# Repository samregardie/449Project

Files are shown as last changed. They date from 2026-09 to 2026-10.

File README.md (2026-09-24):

# 18-449 Project

Lab 2 firmware for the STM32 Nucleo-F401RE, built with Zephyr.

- `lab2/stm32/`: the Zephyr app
- `setup449`: shell setup script (see [Every new shell](#every-new-shell))

This repo sits inside a west workspace:

```
zephyrproject/     ← west workspace (not tracked): .venv/ .west/ zephyr/ modules/
└── 449Project/           ← this repo
```

## One-time setup

1. Follow the [Zephyr getting-started guide](https://docs.zephyrproject.org/latest/develop/getting_started/index.html) to install the host dependencies and the Zephyr SDK.
2. Install [STM32CubeProgrammer](https://www.st.com/en/development-tools/stm32cubeprog.html) (for `west flash`) and OpenOCD (for `west debug`; on macOS run `brew install openocd`).
3. Create the workspace and clone this repo into it:
   ```sh
   mkdir zephyrproject && cd zephyrproject
   python3 -m venv .venv
   source .venv/bin/activate
   pip install west
   west init -m https://github.com/zephyrproject-rtos/zephyr .
   west update
   west packages pip --install
   git clone <this-repo-url> 449Project
   ```

## Every new shell

Run from `449Project/` (bash or zsh):

```sh
source ./setup449
```

It must be sourced, not executed. It activates the west venv and the Zephyr environment.
## Check that your setup works

Build and flash a stock Zephyr sample. The green LED (LD2) should blink:

```sh
west build -p always -b nucleo_f401re ../zephyr/samples/basic/blinky
west flash
```

## Build, flash, debug our app

Run from `449Project/`:

```sh
west build -p always -b nucleo_f401re lab2/stm32   # full rebuild
west flash
west debugserver                                   # terminal 1
west debug                                         # terminal 2
```

For debugging, build with optimizations off:

```sh
west build -p always -b nucleo_f401re lab2/stm32 -- -DCONFIG_DEBUG_OPTIMIZATIONS=y -DCONFIG_DEBUG_THREAD_INFO=y
```

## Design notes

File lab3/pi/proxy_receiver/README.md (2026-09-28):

Code copied from https://github.com/RockyShaikh/logitech-wheel-dev-updated-f26

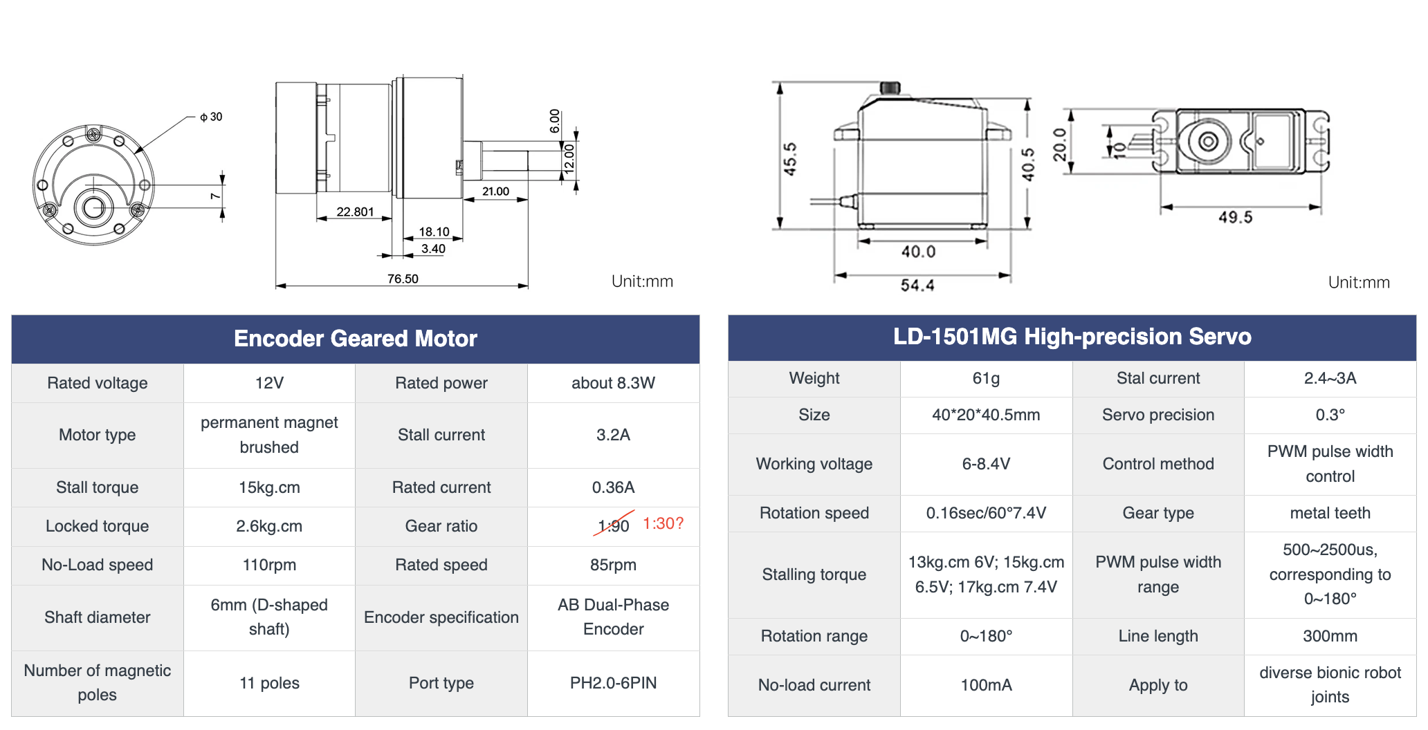
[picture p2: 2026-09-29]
docs/Encoder, Servo datasheet.png

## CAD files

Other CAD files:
docs/CAN Layout.dwg

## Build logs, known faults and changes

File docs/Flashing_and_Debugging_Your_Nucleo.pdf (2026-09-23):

# Flashing and Debugging Your Nucleo

# Installing the Necessary Tools

In order to flash and debug your Nucleo with west, you need to install the proper tooling first. You will need to install the following:

Tool | Description | Notes
STM32CubeProgrammer (https://www.st.com/en/development-tools/stm32cubeprog.html) | STM32CubeProgrammer (STM32CubeProg) is an all-in-one multi-OS software tool for programming STM32 products. | This is required
openocd (https://docs.zephyrproject.org/latest/develop/flash_debug/host-tools.html#runner-openocd) | OpenOCD is a community open source project that provides GDB remote debugging and flash programming support for a wide range of SoCs. | Already installed through Zephyr SDK if using Linux.

## Note about JLink

Some of you may be tempted to use the STM reflasher to flash the JLink firmware onto the STLink. Please do not do that. These boards will eventually get passed down to 18-349, and it may break their workflow.

## References

- Nucleo F401RE (https://docs.zephyrproject.org/latest/boards/st/nucleo_f401re/doc/index.html)

# Setting up your developer environment (every time you open a new terminal)

Every time you open a new terminal, you need to run the following:

Shell

Swift

Shell

# === Linux/Mac ===

# Source the Python environment source .venv/bin/active

# Source the Zephyr environment source zephyr/zephyr-env.sh

# === Windows ===

# Activate the Python environment .venv\Scripts\activate.bat

# Source the Zephyr environment zephyr/zephyr-env.cmd

# Flashing

Flashing your board is very simple. You just run the following command:

west flash

More information on the flash command can be found here. (https://docs.zephyrproject.org/latest/develop/west/build-flash-debug.html#flashing-west-flash)

# Debugging

Debugging on this board can be tedious. You will need two terminals. One for the debug server, and the other for the debugging session. Run the following commands:

# In terminal 1

west debugserver

# In terminal 2

west debug

Shell

Shell

## Build with debug options enabled

west build -b nucleo_f401re/stm32f401xe -- -DCONFIG_DEBUG_OPTIMIZATIONS=y -DCONFIG_DEBUG_THREAD_INFO=y <other cmake options>

## Notes

You may run into a situation where the debugger seems like it is looping to the same breakpoint that you did not set when you start the debugging session. I don’t know why this happens, however, there is a work around. See GDB keeps pausing on `z_arm_reset()`.

# Troubleshooting

## Permission denied in Linux

Problem: udev rules are not installed
Solution: Install the udev rules, reload them, and power cycle the board (unplug and plug back in)

wget -O 60-openocd.rules
https://sf.net/p/openocd/code/ci/master/tree/contrib/60-openocd.rules?format=raw sudo cp 60-openocd.rules /etc/udev/rules.d
sudo udevadm control --reload

## Weird error message if using openocd as a runner

Problem:

Solution: Upgrade the STLink firmware
1. Open STM32CubeProgrammer

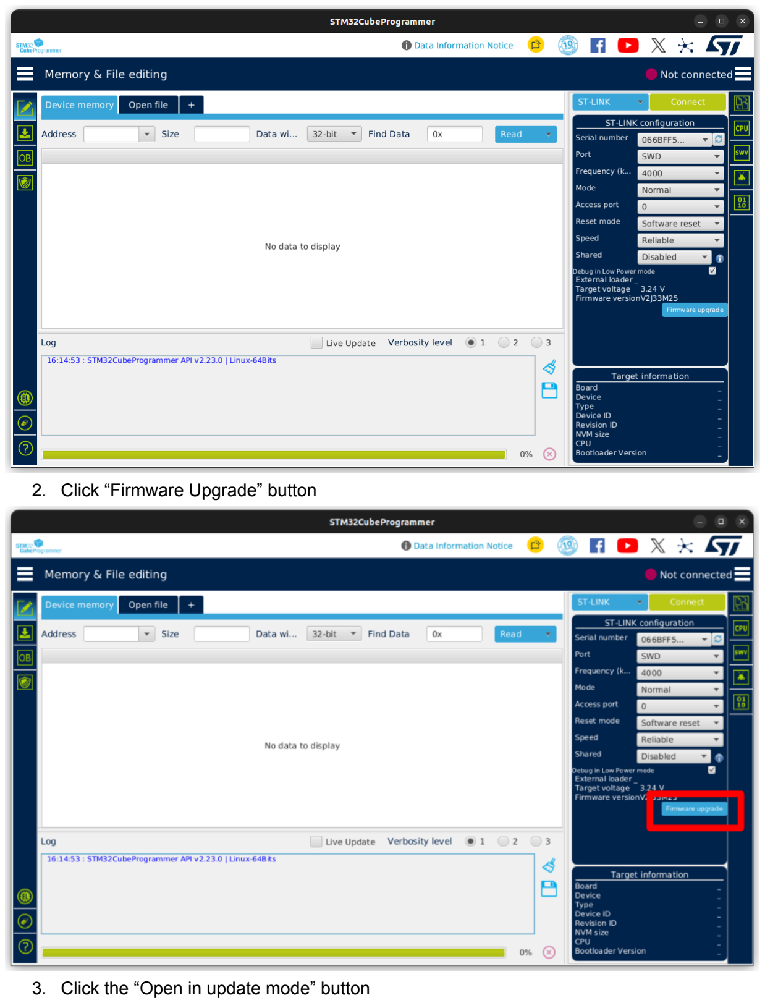
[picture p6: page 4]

2. Click “Firmware Upgrade” button
3. Click the “Open in update mode” button

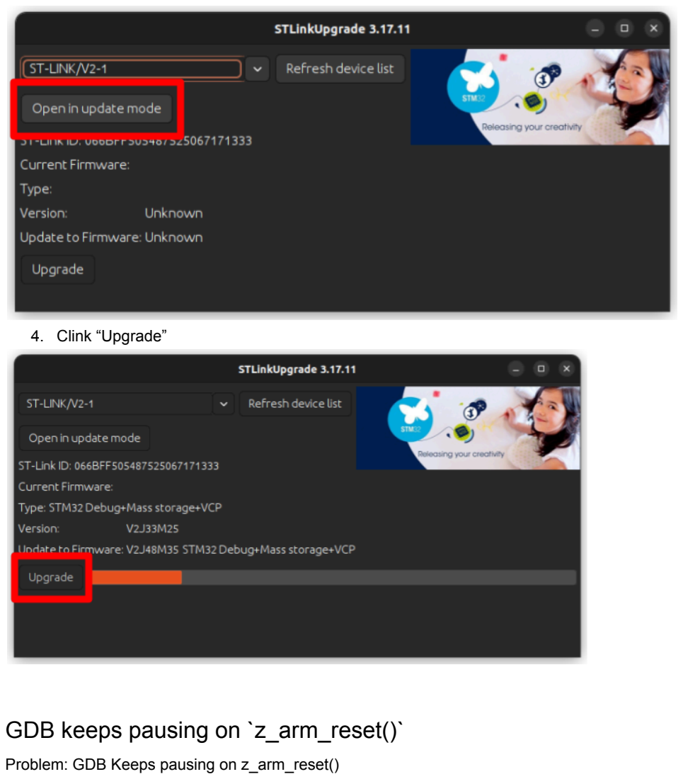
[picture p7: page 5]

4. Clink “Upgrade”

## GDB keeps pausing on `z_arm_reset()`

Problem: GDB Keeps pausing on z_arm_reset()

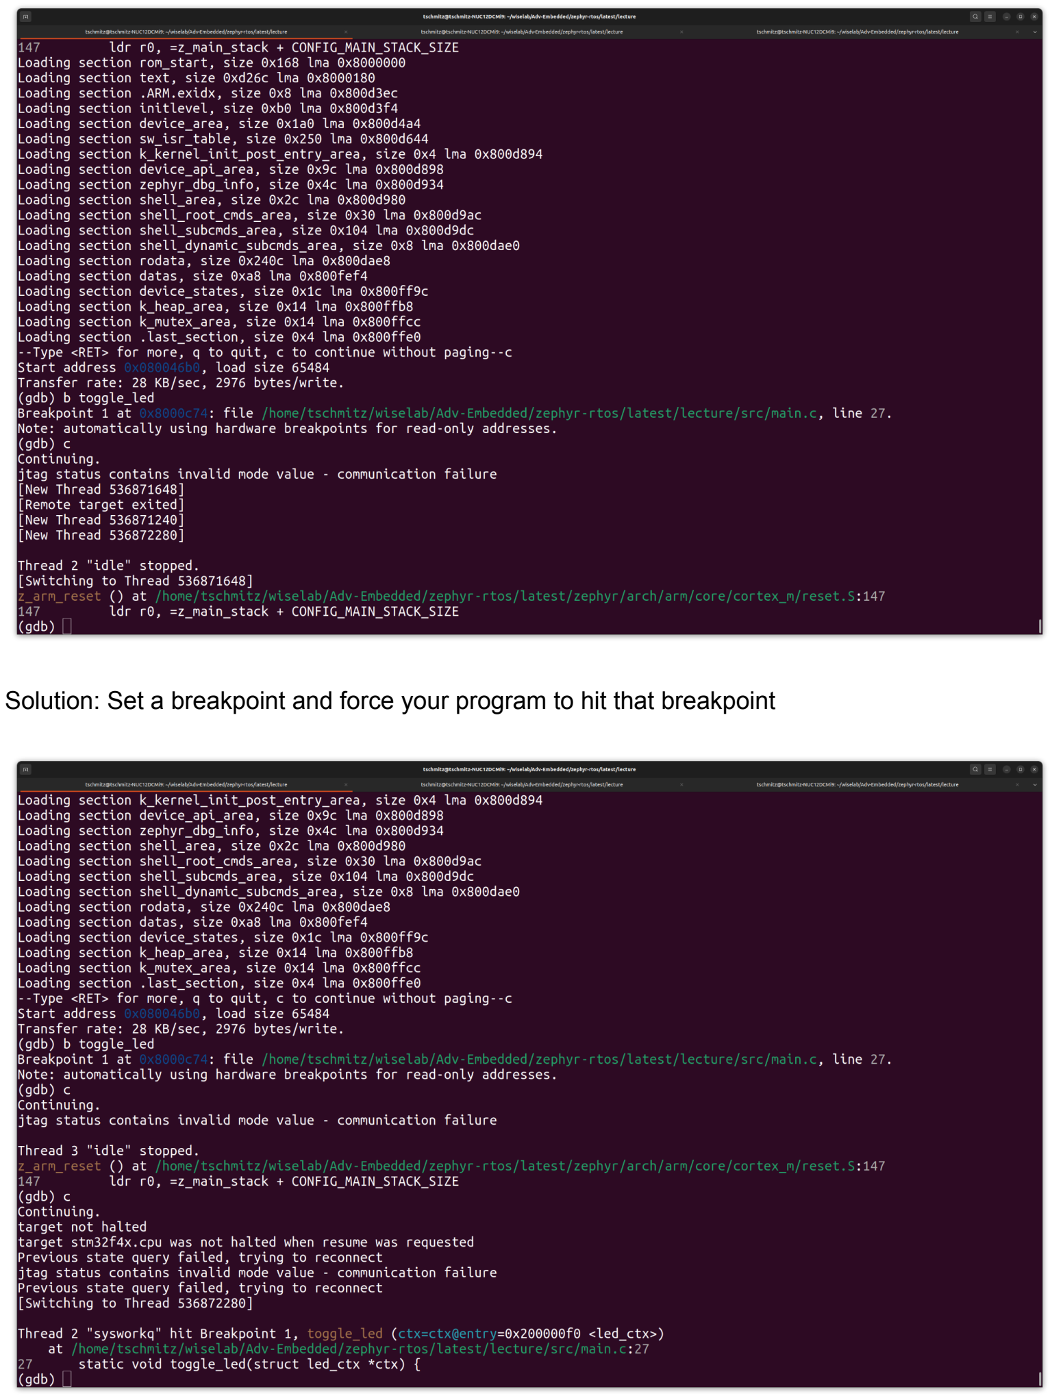
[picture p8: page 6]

Solution: Set a breakpoint and force your program to hit that breakpoint

After it hits that first breakpoint, it should stop pausing on z_arm_reset()

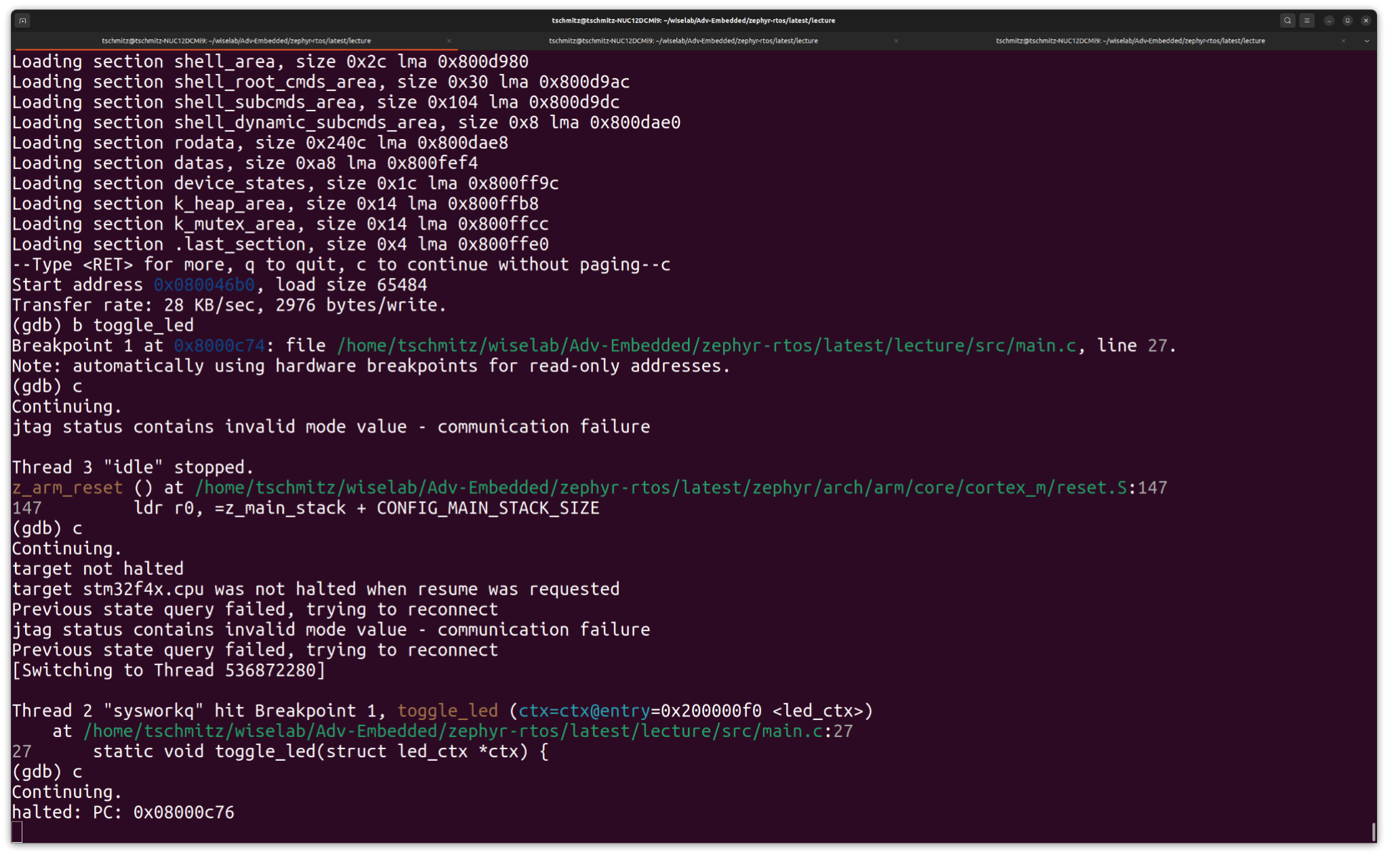
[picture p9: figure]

### Notes

- This may take a few attempts. STLink and OpenOCD are not the best when it comes to debugging…
- Debugging the main thread works perfectly fine until it exits or sleeps forever. Then you are back in the same situation where things are constantly restarting.
- If things are still not working, you can try updating the STLink firmware. Steps found in the previous section.
- If the debug server stops working, just stop it and restart it.

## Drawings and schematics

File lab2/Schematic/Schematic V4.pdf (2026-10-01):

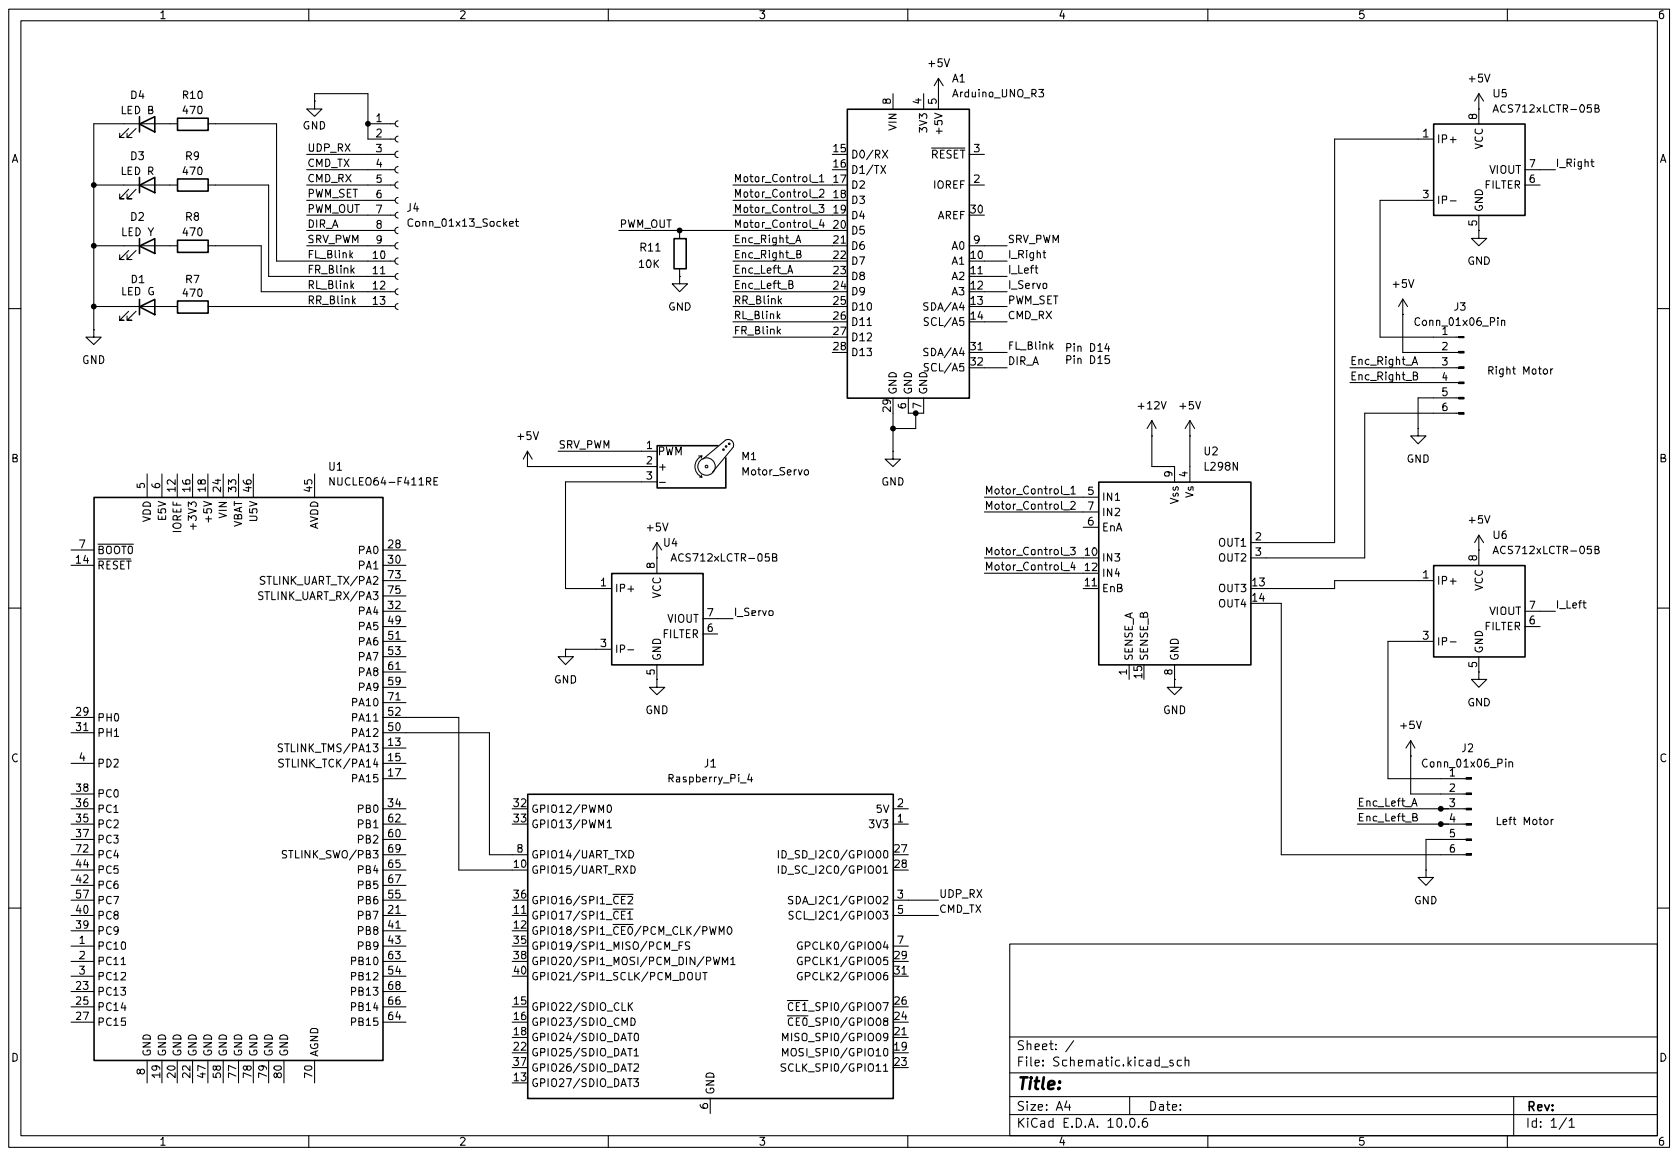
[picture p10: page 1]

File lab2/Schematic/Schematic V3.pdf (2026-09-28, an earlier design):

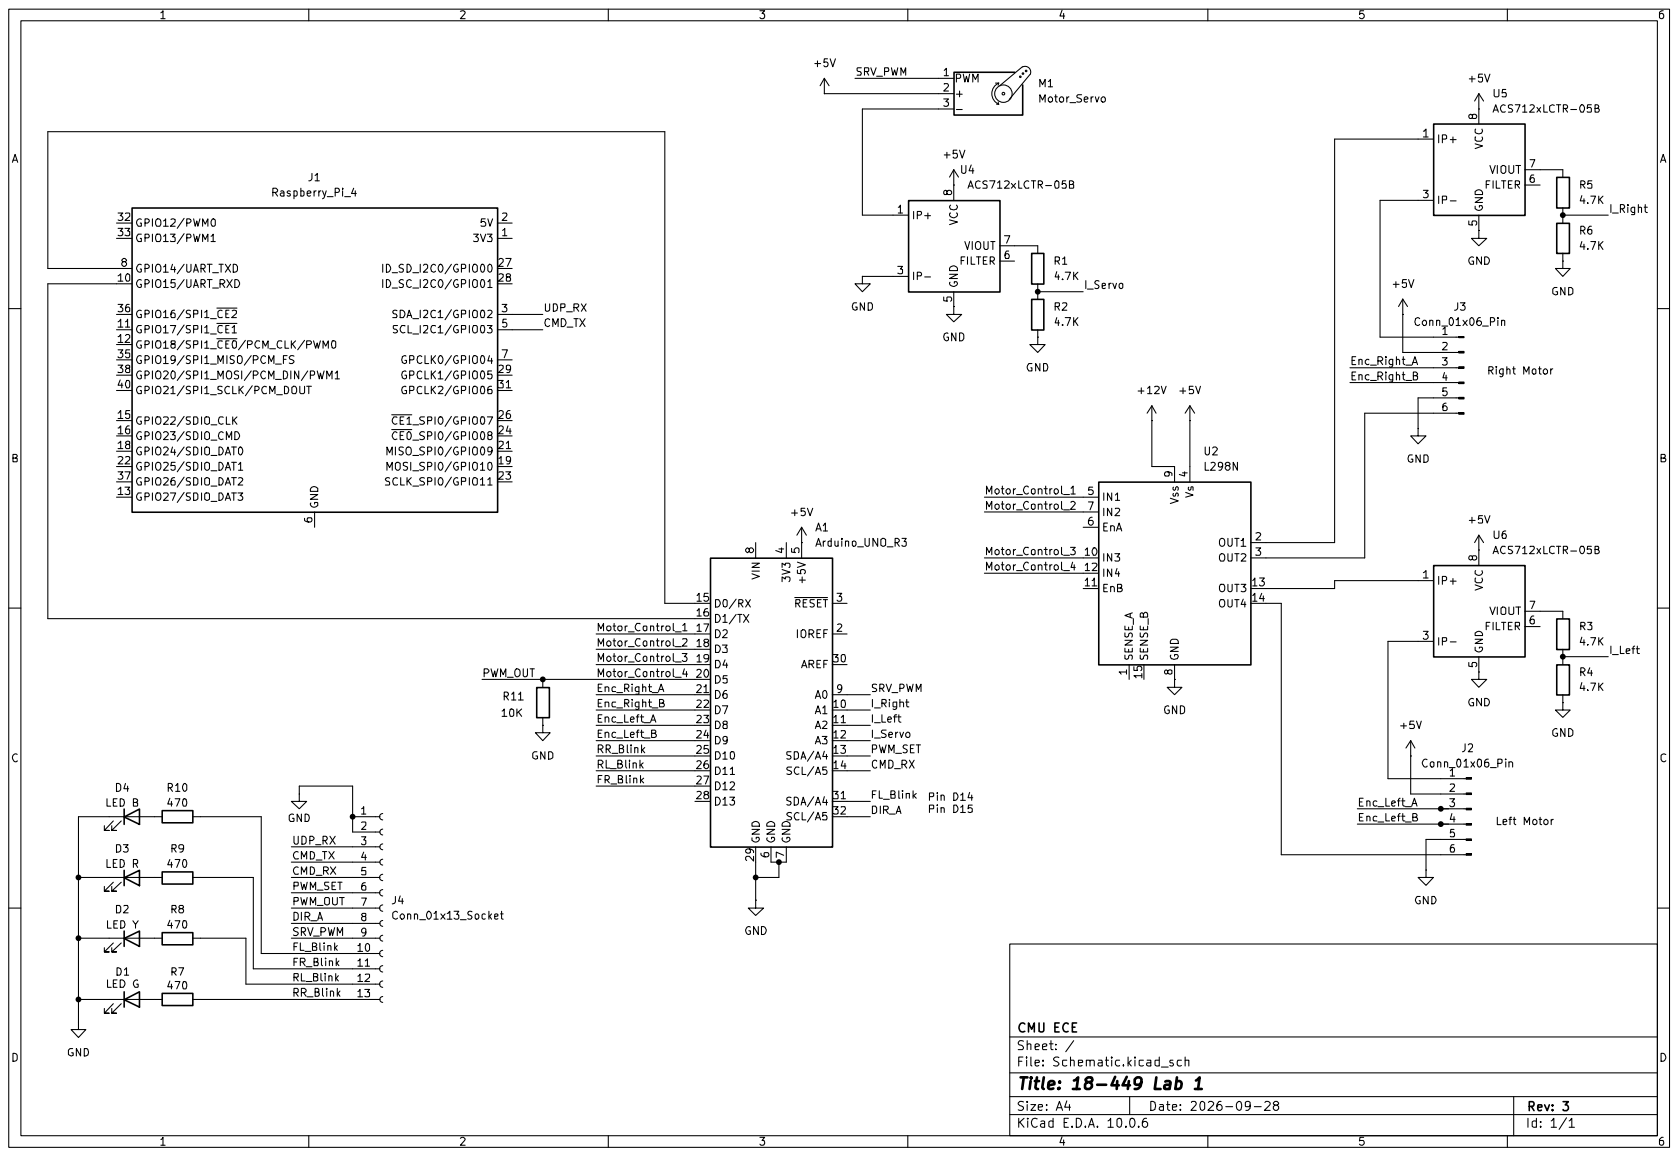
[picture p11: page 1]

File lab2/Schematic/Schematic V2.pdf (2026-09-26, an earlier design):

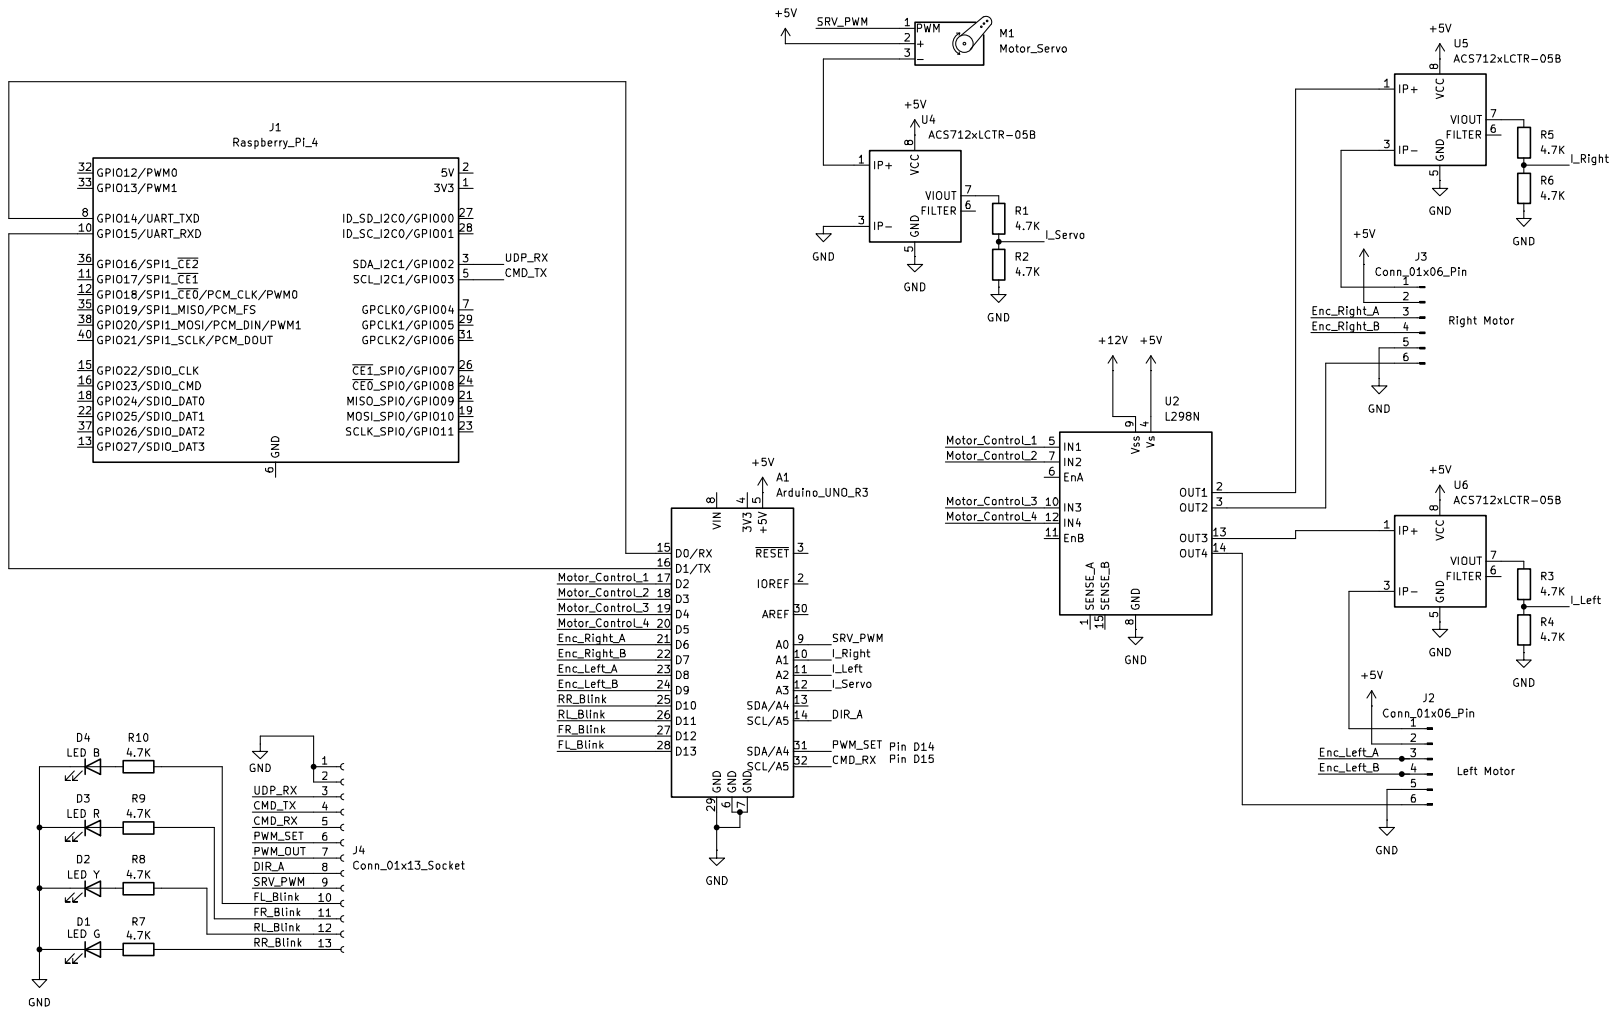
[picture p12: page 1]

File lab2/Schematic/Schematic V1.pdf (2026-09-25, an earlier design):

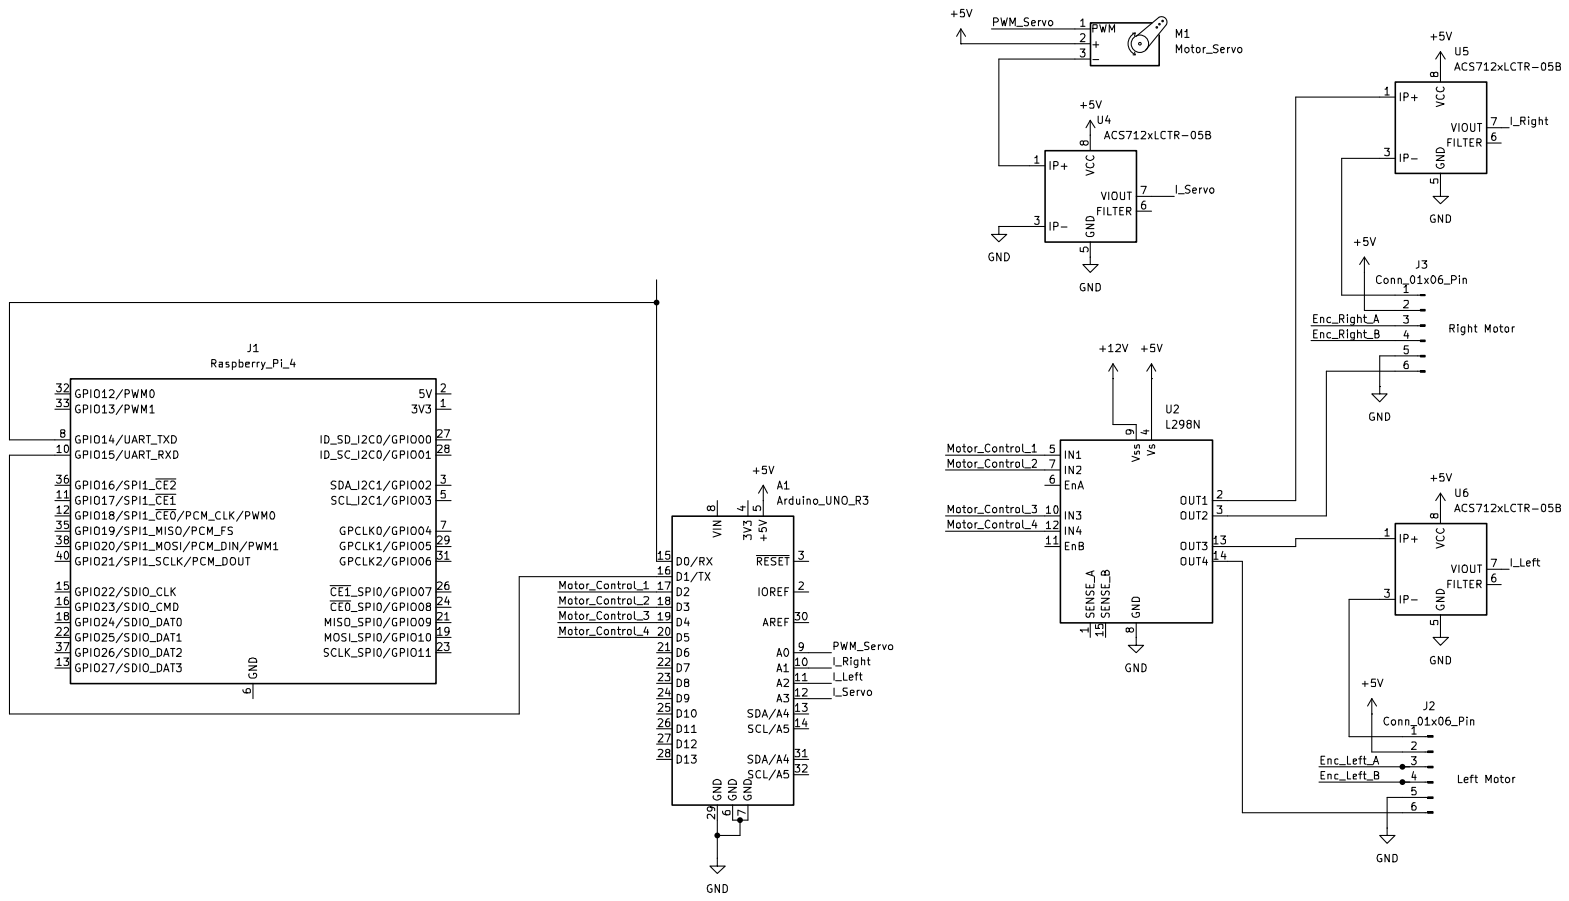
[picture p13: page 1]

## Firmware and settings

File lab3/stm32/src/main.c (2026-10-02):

#include <zephyr/kernel.h>
#include <zephyr/sys/printk.h>

#include "blinker.h"
#include "drive.h"
#include "current.h"
#include "errorstate.h"
#include "servo.h"
#include "picom.h"
#include "status.h"

int main(void)
{
	if (current_sense_init() != 0 || 
		drive_init() != 0 || 
		blinker_init() != 0 || 
		servo_init() != 0 ||
		picom_init() != 0 ||
		status_init() != 0) {
		printk("init failed\n");
		return 1;
	}

	return 0;
}

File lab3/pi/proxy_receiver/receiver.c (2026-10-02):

#include <stdint.h>
#include <fcntl.h>
#include <unistd.h>
#include <termios.h>
#include <stdbool.h>
#include <pigpio.h>
#include <errno.h>

#include <stdio.h>
#include <stdlib.h>
#include <unistd.h>
#include <string.h>
#include <sys/types.h>
#include <sys/socket.h>
#include <arpa/inet.h>
#include <netinet/in.h>
#include "pthread.h"
#include <inttypes.h>

#include "state.h"

/** Configure this **/
#define LOCAL_HOST "172.26.166.54" // IP of local interface
#define R_PORT 8000

#define REMOTE_HOST "172.26.34.95"
#define S_PORT 8001
/** **/

#define UDP_RX_GPIO 2
#define CMD_TX_GPIO 3

#define TX_INTERVAL_MS 300
#define STATE_SIZE sizeof(DIJOYSTATE2_t)

#define UART_BAUD 115200
#define MAG_INT16_MIN 32768

#define STATUS_FRAME_LEN 5

void *send_force(void *arg)
{
  int8_t force = 0;
  int uart_fd = *(int *)arg;
  int sockfd;
  struct sockaddr_in servaddr;

  servaddr.sin_family = AF_INET;
  servaddr.sin_port = htons(S_PORT);
  servaddr.sin_addr.s_addr = inet_addr(REMOTE_HOST);

  if ((sockfd = socket(AF_INET, SOCK_DGRAM, 0)) < 0)
  {
    perror("failed to create socket");
    exit(EXIT_FAILURE);
  }

  int8_t frame[16];
  size_t len = 0;

  while (1)
  {
    int8_t byte;
    ssize_t n = read(uart_fd, &byte, 1);

    if (n < 0)
    {
      if (errno == EINTR)
        continue;
      perror("uart read");
      break;
    }
    
    if (len == sizeof(frame))
      len = 0; // no terminator found; drop and resync
    frame[len++] = byte;

    if (byte == 0x7F) {
      if (len == STATUS_FRAME_LEN) {
        int8_t force = (int8_t)frame[2];
        printf("Motor Left: %d, Motor Right: %d, Servo: %d, Status: %08b\n", frame[0], frame[1], force, frame[3]);
        //sendto(sockfd, &force, 1, 0,
        //       (struct sockaddr *)&servaddr, sizeof(servaddr));
      }
      len = 0;
    }
  }
}

int uart_open(const char *dev, speed_t baud)
{
  int fd = open(dev, O_RDWR | O_NOCTTY);
  if (fd < 0)
  {
    perror("open");
    return -1;
  }

  struct termios tty;
  if (tcgetattr(fd, &tty) != 0)
  {
    perror("tcgetattr");
    close(fd);
    return -1;
  }

  cfmakeraw(&tty); // raw mode: no translation of bytes
  cfsetispeed(&tty, baud);
  cfsetospeed(&tty, baud);

  tty.c_cflag |= CLOCAL | CREAD; // ignore modem lines, enable receiver
  tty.c_cflag &= ~CSTOPB;        // 1 stop bit
  tty.c_cflag &= ~PARENB;        // no parity
  tty.c_cflag &= ~CRTSCTS;       // no hardware flow control

  tty.c_cc[VMIN] = 0;   // read() returns immediately...
  tty.c_cc[VTIME] = 10; // ...or after 1 s timeout (tenths of a second)

  if (tcsetattr(fd, TCSANOW, &tty) != 0)
  {
    perror("tcsetattr");
    close(fd);
    return -1;
  }
  return fd;
}

int main()
{
  int sockfd;
  char buffer[STATE_SIZE + 1];

  struct sockaddr_in servaddr = {0};

  // Initialize GPIO
  gpioInitialise();
  gpioSetMode(UDP_RX_GPIO, PI_OUTPUT); // Set GPIO2 as input.
  gpioSetMode(CMD_TX_GPIO, PI_OUTPUT); // Set GPIO3 as input.

  gpioWrite(UDP_RX_GPIO, PI_LOW);
  gpioWrite(CMD_TX_GPIO, PI_LOW);

  int uart_fd = uart_open("/dev/serial0", UART_BAUD);

  if ((sockfd = socket(AF_INET, SOCK_DGRAM, 0)) < 0)
  {
    perror("failed to create socket");
    exit(EXIT_FAILURE);
  }

  servaddr.sin_family = AF_INET;
  servaddr.sin_port = htons(R_PORT);
  servaddr.sin_addr.s_addr = inet_addr(LOCAL_HOST);

  if (bind(sockfd, (const struct sockaddr *)&servaddr,
           sizeof(servaddr)) < 0)
  {
    perror("bind failed");
    exit(EXIT_FAILURE);
  }

  DIJOYSTATE2_t state;
  char recvbuf[sizeof(DIJOYSTATE2_t) + 4];
  pthread_t send_tid;
  pthread_create(&send_tid, NULL, send_force, &uart_fd);

  write(uart_fd, "Test from Pi\n\x7F", 14);

  while (1)
  {
    // printf("Wait recv\n");
    int n, len;
    n = recvfrom(sockfd, recvbuf, STATE_SIZE, MSG_WAITALL,
                 (struct sockaddr *)&servaddr, &len);
    gpioWrite(UDP_RX_GPIO, !gpioRead(UDP_RX_GPIO)); // Toggle the gpio when read complete
    uint32_t packet_ct = ((uint32_t *)recvbuf)[0];
    memcpy(&state, recvbuf + 4, sizeof(state));
    // printf("Receive state (Pkt: %8X) :  Wheel: %d | Throttle: %d | Brake: %d\n", packet_ct, state.lX, state.lY, state.lRz);

    // Data scaling for stm32
    int8_t steer = state.lX / ((MAG_INT16_MIN + 99) / 100);    // Denominator is division by 100 but always round up
    int8_t throttle = state.lY / ((MAG_INT16_MIN + 99) / 100); // Denominator is division by 100 but always round up
    int8_t brake = state.lRz / ((MAG_INT16_MIN + 99) / 100);   // Denominator is division by 100 but always round up
    bool left_signal = state.rgbButtons[5];
    bool right_signal = state.rgbButtons[4];
    bool error_button = state.rgbButtons[1];

    // throttle = (2*throttle) - 100;	// shift from 0 to 100 to -100 to 100
    // brake = (2*brake) - 100;		// shift from 0 to 100 to -100 to 100

    //printf("steer=%d, throttle=%d, brake=%d, left=%d, right=%d, error=%d \n", steer, throttle, brake, left_signal, right_signal, error_button);

    // Send data over uart
    uint8_t buf[] = {steer, throttle, brake, left_signal, right_signal, error_button, '\n', 0x7F};
    write(uart_fd, buf, sizeof(buf));
    gpioWrite(CMD_TX_GPIO, !gpioRead(CMD_TX_GPIO)); // Toggle the gpio on write
    //printf("%s\n", buf);
  }

  return 0;
}

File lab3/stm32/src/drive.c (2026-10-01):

/*
 * Velocity control: throttle -> target velocity, PI on the average of the two
 * encoders, brake beats throttle.
 *
 * drive_command() and drive_set_error() only store the request. The control
 * thread is the only code that writes to the motors: every 1 ms it samples
 * the encoders, reads the request and either brakes or runs the PI. The 1 ms
 * period keeps command -> PWM_SET under the 2 ms limit.
 *
 * PWM_SET toggles only on the tick that first applies a new command, so
 * CMD_RX -> PWM_SET on the scope is the software response time, for both
 * throttle and brake. (DIR_A has no edge when braking from forward: forward
 * and brake both hold DIR low.)
 */

#include <stdlib.h>

#include <zephyr/kernel.h>
#include <zephyr/drivers/gpio.h>

#include "drive.h"
#include "encoder.h"
#include "motor.h"

/* Linear: full throttle = 30 ticks per 10 ms (~40% of the measured max) */
#define MAX_VELOCITY 30.0f
#define THROTTLE_DEADBAND 2	/* |throttle| below this (i.e. +/-1%) means 0 */

/* PI gains: velocity error (ticks per 10 ms) -> duty. TODO (team): tune */
#define KP 20.0f
#define KI 100.0f

#define DT (ENCODER_SAMPLE_MS / 1000.0f)	/* seconds per tick */

static const struct gpio_dt_spec tp_pwm_set =
	GPIO_DT_SPEC_GET(DT_PATH(zephyr_user), pwm_set_gpios);

/* Shared between the control thread and callers, always under the lock */
static struct k_spinlock lock;
static int32_t throttle;
static bool brake;
static bool error = true;	/* power-up is the error state */
static uint32_t seq;		/* bumped on every accepted command */
static struct drive_status status;

/* Only touched by the control thread */
static float integral;

static float throttle_to_target(int32_t t)
{
	if (abs(t) < THROTTLE_DEADBAND) {
		return 0.0f;
	}

	return t * MAX_VELOCITY / DRIVE_THROTTLE_MAX;
}

static int32_t pi_update(float target, float velocity)
{
	float err = target - velocity;
	float out = KP * err + KI * integral;

	/* Anti-windup: don't integrate further into saturation */
	bool saturated = (out >= MOTOR_DUTY_MAX && err > 0) ||
			 (out <= -MOTOR_DUTY_MAX && err < 0);

	if (!saturated) {
		integral += err * DT;
	}

	return (int32_t)CLAMP(out, -MOTOR_DUTY_MAX, MOTOR_DUTY_MAX);
}

K_SEM_DEFINE(start_sem, 0, 1);
K_TIMER_DEFINE(loop_timer, NULL, NULL);

static void control_loop(void *p1, void *p2, void *p3)
{
	uint32_t applied_seq = 0;

	/* Wait until drive_init() has set up the motors and encoders */
	k_sem_take(&start_sem, K_FOREVER);
	k_timer_start(&loop_timer, K_MSEC(ENCODER_SAMPLE_MS), K_MSEC(ENCODER_SAMPLE_MS));

	while (1) {
		k_timer_status_sync(&loop_timer);
		encoder_sample();

		k_spinlock_key_t key = k_spin_lock(&lock);
		int32_t t = throttle;
		bool stop = brake || error;
		uint32_t s = seq;

		k_spin_unlock(&lock, key);

		float velocity = (encoder_velocity(SIDE_LEFT) + encoder_velocity(SIDE_RIGHT)) / 2.0f;
		float target = 0.0f;
		int32_t duty = 0;

		if (stop) {
			motor_brake();
			integral = 0.0f;	/* so releasing the brake doesn't lurch */
		} else {
			target = throttle_to_target(t);
			duty = pi_update(target, velocity);
			motor_set(SIDE_LEFT, duty);
			motor_set(SIDE_RIGHT, duty);
		}

		/* First write after a new command: mark it for the scope */
		if (s != applied_seq) {
			gpio_pin_toggle_dt(&tp_pwm_set);
			applied_seq = s;
		}

		key = k_spin_lock(&lock);
		status = (struct drive_status){ target, velocity, duty };
		k_spin_unlock(&lock, key);
	}
}

/* Preemptive: higher-priority threads and ISRs can interrupt a tick */
K_THREAD_DEFINE(drive_thread, 1024, control_loop, NULL, NULL, NULL, K_PRIO_PREEMPT(2), 0, 0);

int drive_init(void)
{
	/* Motors first, so they're braked before anything else runs */
	int ret = motor_init();

	if (ret < 0) {
		return ret;
	}

	if (!gpio_is_ready_dt(&tp_pwm_set)) {
		return -ENODEV;
	}

	ret = gpio_pin_configure_dt(&tp_pwm_set, GPIO_OUTPUT_INACTIVE);
	if (ret < 0) {
		return ret;
	}

	ret = encoder_init();
	if (ret < 0) {
		return ret;
	}

	k_sem_give(&start_sem);
	return 0;
}

void drive_command(int32_t new_throttle, bool new_brake)
{
	k_spinlock_key_t key = k_spin_lock(&lock);

	/* Ignored in the error state */
	if (!error) {
		throttle = CLAMP(new_throttle, -DRIVE_THROTTLE_MAX, DRIVE_THROTTLE_MAX);
		brake = new_brake;
		seq++;
	}

	k_spin_unlock(&lock, key);
}

void drive_set_error(bool new_error)
{
	k_spinlock_key_t key = k_spin_lock(&lock);

	/* Either way, start again from a standstill */
	error = new_error;
	throttle = 0;
	brake = false;
	seq++;

	k_spin_unlock(&lock, key);
}

struct drive_status drive_get_status(void)
{
	k_spinlock_key_t key = k_spin_lock(&lock);
	struct drive_status s = status;

	k_spin_unlock(&lock, key);
	return s;
}

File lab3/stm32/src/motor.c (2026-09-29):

/*
 * L298N H-bridge. ENA/ENB are tied high; IN1/IN3 take PWM, IN2/IN4 are DIR.
 */

#include <zephyr/kernel.h>
#include <zephyr/drivers/gpio.h>
#include <zephyr/drivers/pwm.h>

#include "motor.h"

#define USER_NODE DT_PATH(zephyr_user)

/* Indexed by enum side */
static const struct pwm_dt_spec pwm[] = {
	[SIDE_LEFT] = PWM_DT_SPEC_GET_BY_NAME(USER_NODE, motor_left),
	[SIDE_RIGHT] = PWM_DT_SPEC_GET_BY_NAME(USER_NODE, motor_right),
};

static const struct gpio_dt_spec dir[] = {
	[SIDE_LEFT] = GPIO_DT_SPEC_GET(USER_NODE, motor_left_dir_gpios),
	[SIDE_RIGHT] = GPIO_DT_SPEC_GET(USER_NODE, motor_right_dir_gpios),
};

/* Test points */
static const struct gpio_dt_spec tp_dir_a = GPIO_DT_SPEC_GET(USER_NODE, dir_a_gpios);

int motor_init(void)
{
	const struct gpio_dt_spec *outputs[] = { &dir[SIDE_LEFT], &dir[SIDE_RIGHT], &tp_dir_a };

	for (int i = 0; i < ARRAY_SIZE(outputs); i++) {
		if (!gpio_is_ready_dt(outputs[i])) {
			return -ENODEV;
		}

		int ret = gpio_pin_configure_dt(outputs[i], GPIO_OUTPUT_INACTIVE);

		if (ret < 0) {
			return ret;
		}
	}

	/* PWM low and DIR low with EN tied high: both motors start braked */
	for (int i = 0; i < ARRAY_SIZE(pwm); i++) {
		if (!pwm_is_ready_dt(&pwm[i])) {
			return -ENODEV;
		}

		int ret = pwm_set_pulse_dt(&pwm[i], 0);

		if (ret < 0) {
			return ret;
		}
	}

	return 0;
}

/*
 * The motors face opposite ways, so the same polarity turns the wheels in
 * opposite directions. Set true for a side whose wheel runs backwards.
 */
static const bool reversed[] = {
	[SIDE_LEFT] = false,
	[SIDE_RIGHT] = false,
};

/* DIR_A mirrors the channel A direction pin (IN2, right motor) */
static void write_dir(enum side s, bool high)
{
	gpio_pin_set_dt(&dir[s], high);

	if (s == SIDE_RIGHT) {
		gpio_pin_set_dt(&tp_dir_a, high);
	}
}

/*
 * With EN high, IN1 = IN2 is a brake and IN1 != IN2 drives:
 *   DIR low:  PWM high drives, PWM low brakes -> pulse = duty
 *   DIR high: PWM low drives, PWM high brakes -> pulse = MAX - duty
 */
void motor_set(enum side s, int32_t duty)
{
	duty = CLAMP(duty, -MOTOR_DUTY_MAX, MOTOR_DUTY_MAX);

	if (reversed[s]) {
		duty = -duty;
	}

	bool dir_high = duty < 0;
	uint32_t on = dir_high ? MOTOR_DUTY_MAX + duty : duty;
	uint32_t pulse = (uint64_t)pwm[s].period * on / MOTOR_DUTY_MAX;

	write_dir(s, dir_high);
	pwm_set_pulse_dt(&pwm[s], pulse);
}

/* IN1 = IN2 = low: PWM off and both motor terminals shorted together */
void motor_brake(void)
{
	for (int s = 0; s < ARRAY_SIZE(pwm); s++) {
		pwm_set_pulse_dt(&pwm[s], 0);
		write_dir(s, false);
	}
}

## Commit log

2026-09-23 Putting in documentation from lab 1
    [CAN Layout.dwg]
2026-09-23 stubs for stm32 (zephyr project)
2026-09-25 Schematic updated to current wiring
    [18449 Lab 2.kicad_pcb, 18449 Lab 2.kicad_sch]
2026-09-26 Finished first draft of schematic
    [Schematic.kicad_pcb, Schematic.kicad_sch]
2026-09-26 Delete 18449 Lab 2 directory
    This directory was created on accident when I first started playing with Kicad, and has no relevant files.
    [18449 Lab 2.kicad_pcb, 18449 Lab 2.kicad_sch]
2026-09-28 first pass of pin assignments
2026-09-28 update devicetree and gitignore
2026-09-28 encoder, servo datasheet
2026-09-28 motor stubs
2026-09-28 Fixed local IP in receiver.c. Added build.sh for recomplie with new IPs.
    [receiver.c]
2026-09-28 working test of motors
2026-09-28 working encoder counts
2026-09-28 Schematic V3
    [Schematic.kicad_sch]
2026-09-29 Current ADC initially working
2026-09-29 encoder velocity updated
2026-09-29 encoder resolution test
2026-09-29 move PWM_SET out of motor.c
2026-09-29 pid start
2026-09-29 clean up and tune PID
2026-09-30 Update Schematic V4
    [Schematic.kicad_sch]
2026-09-30 Interupt UART implementation courtesy of Claude.
2026-09-30 Mapping of wheel buttons to btn id for mac_proxy.py
2026-09-30 servo code
2026-10-01 Added data formating and forwarding to raspberry pi.
2026-10-01 Added uart echo to main.
2026-10-01 Added missing null terminator in test message.
    [main.c]
2026-10-01 Added UART to prj.conf
2026-10-01 Current sensing kind of working but way too much noise
    [current.c, main.c]
2026-10-01 Added logic to toggle GPIO on UDP reat and UART write
2026-10-01 fixed init calls - return 0 on success
    [current.c, main.c]
2026-10-01 Set throttle and brake range to -100 to 100
2026-10-01 change drive thread to preemptive
2026-10-01 status frame
2026-10-01 current sensor scaling, averaging
2026-10-02 pi reciever.c now parses the uart status feedback. Fixed bug in picom_send to add terminator to message.
    [picom.c, receiver.c]
2026-10-02 Removed print statement debugging and fixed status printout.
    [receiver.c]
2026-10-08 Made folder for lab 3
    [Schematic.kicad_pcb, Schematic.kicad_sch]
2026-10-19 App overlay for stm_front alt spi pins(D3-5), int on D6&D7, and CS on D9&D10
2026-10-20 First set of changes for CAN PCB
2026-10-20 Device tree correct. CAN-counter local echo example working on both CAN channels.
2026-10-21 add stm32 can test, working
2026-10-22 added pin assignments md file
2026-10-22 shortcuts for stm32 build, update readme
2026-10-22 first pass at relay
2026-10-23 Schematic tenativley complete for CAN lab
2026-10-25 Schematic 1.0
2026-10-25 Schematic 1.1 for small componet value issues
2026-10-26 Schematic Updates
2026-10-26 Updated pin definitions and NC to have 0 ERC errors. Still many warnings, most of which are footprint library related.
2026-10-29 Initial Board layout complete and DRC passes
2026-10-29 Thicker motor power traces.
2026-10-30 Power input and protections done with pours.
2026-10-30 Initial pin assignment change.
2026-10-30 Logic level and v-reg for leds. Motor Driver heatsink. Fixed pth vs sm footprints. Misc.
2026-10-30 Reworked ground at L298N
2026-11-01 Fixed missing trace. Added iBoM.
2026-11-01 Updated Gerbers and Submission folder.
2026-11-02 Moved flyback diodes to the output side of Current ICs.
2026-11-12 add lab5 handout, remove stm32-can-test
